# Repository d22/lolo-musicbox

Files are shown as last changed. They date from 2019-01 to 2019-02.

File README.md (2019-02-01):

# Lolo Musicbox
A simple Raspberry Pi NFC musicbox for children, the NFC tags trigger songs or playlists.

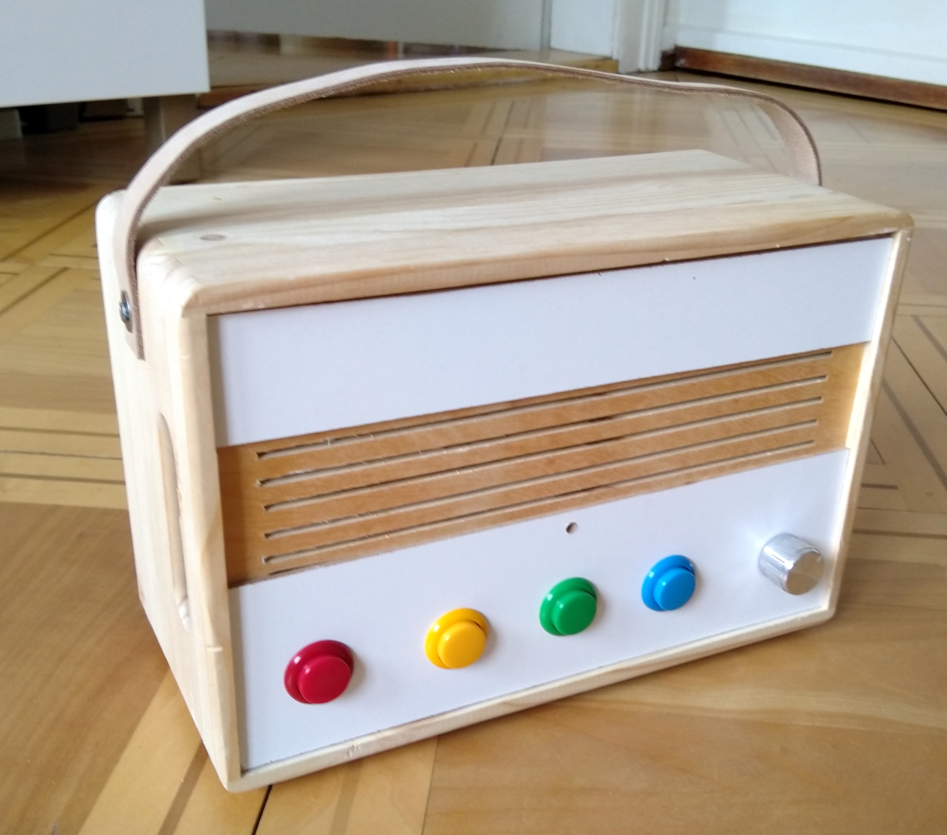
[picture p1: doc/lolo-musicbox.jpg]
lolo-musicbox

Finished product.

lolo-musicbox-inisde
Inside the box.

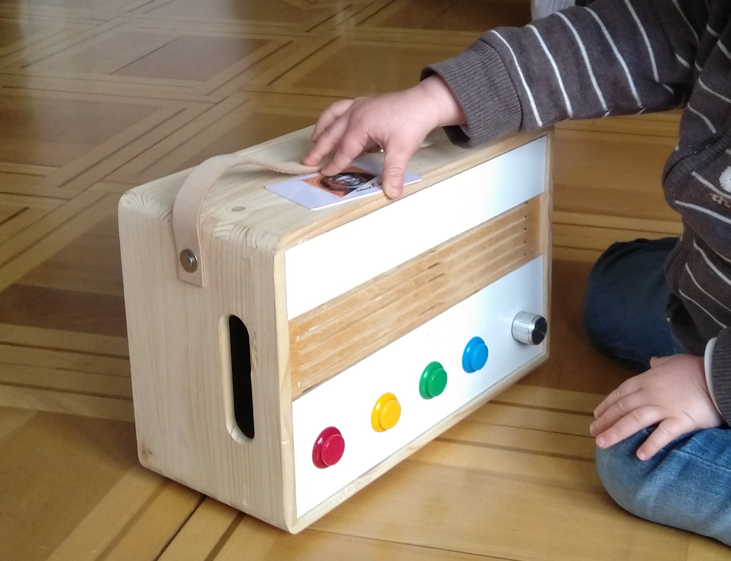
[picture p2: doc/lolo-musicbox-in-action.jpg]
lolo-musicbox-inisde

In action.

## Software Setup
Ten steps to setup the Lolo-Musicbox. Some of them will be explained in detail:
1. Prepare SD with Raspbian
1. Configure WIFI and SSH
1. Boot up the Raspberry Pi, connect via SSH, use raspi-conf for basic setup
1. Install Git
1. Clone this repo
1. Run `setup.sh`
1. check `config.py`
1. Reboot the Raspberry Pi
1. Copy music onto the Lolo-Musicbox
1. Enjoy

### Prepare SD with Raspbian
Tested with 'Raspbian Stretch Lite', see https://www.raspberrypi.org/downloads/raspbian/

### Configure WIFI and SSH
To activate WIFI and SSH without booting the Raspberry Pi add the two files
to the root directory of the SD.

* To activate SSH add an empty file with the name `ssh`
* To configure and activate WIFI add a file with the name `wpa_supplicant.conf`,
containing the WIFI configuration.
```
country=US
ctrl_interface=DIR=/var/run/wpa_supplicant GROUP=netdev
update_config=1

network={
    ssid="<the-ssid-of-your-network>"
    scan_ssid=1
    psk="<the-password-to-your-network>"
    key_mgmt=WPA-PSK
}
```

### Basic setup with raspi-config
```
sudo raspi-config
```
* Change password: 1.
* Set new hostname to 'lolo': 2.N1.
* Don't wait for network on boot: 3.B1. No
* Set locale: 4.I1
* Set WIFI Country: 4.I4

### Install Git
```
sudo apt-get update && sudo apt-get install git
```

### Clone this repo
```
cd ~
git clone <url> lolo
```

### Run `setup.sh`
This installs the required software, registers the Lolo-Musicbox service, and 
tries to optimize the boot time.
``` 
cd ~/lolo
chmod +x setup.sh
./setup.sh
```

### Check `config.py`
All paths and GPIO pins are defined in `config.py`. Just check if the current setup,
hardware and software, matches the given values in `config.py`.

### Copy music onto the Lolo-Musicbox
See 'How the Lolo-Musicbox' works.

### Enjoy
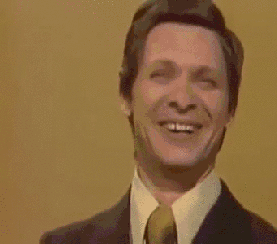
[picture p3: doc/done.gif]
done


## Hardware setup
The musicbox is based on a Raspberry Pi 3+. Additionally I used the following parts:

* MFRC522 RFID/NFC module (library [on Github](https://github.com/ondryaso/pi-rc522))
* MCP3008, 8-Channel 10-Bit ADC to control the volume with a potentiometer 
(see: [Adafruit tutorial](https://learn.adafruit.com/reading-a-analog-in-and-controlling-audio-volume-with-the-raspberry-pi))
* TPA2012, Stereo 2.1W Class D Audio Amplifier (see [Adafruit](https://www.adafruit.com/product/1552))
* 4 arcade buttons
* RGB LED (with according resistors)
* 2 small 4Ω speakers
* 3.5mm audio jack breakout
* 2 NCR18650B LiIon batteries (3.7V)
* TP4056 LiPo battery charger module
* MT3608, DC-DC Step Up Converter, to step up the 3.7V from the batteries to 5V needed by the Raspberry Pi

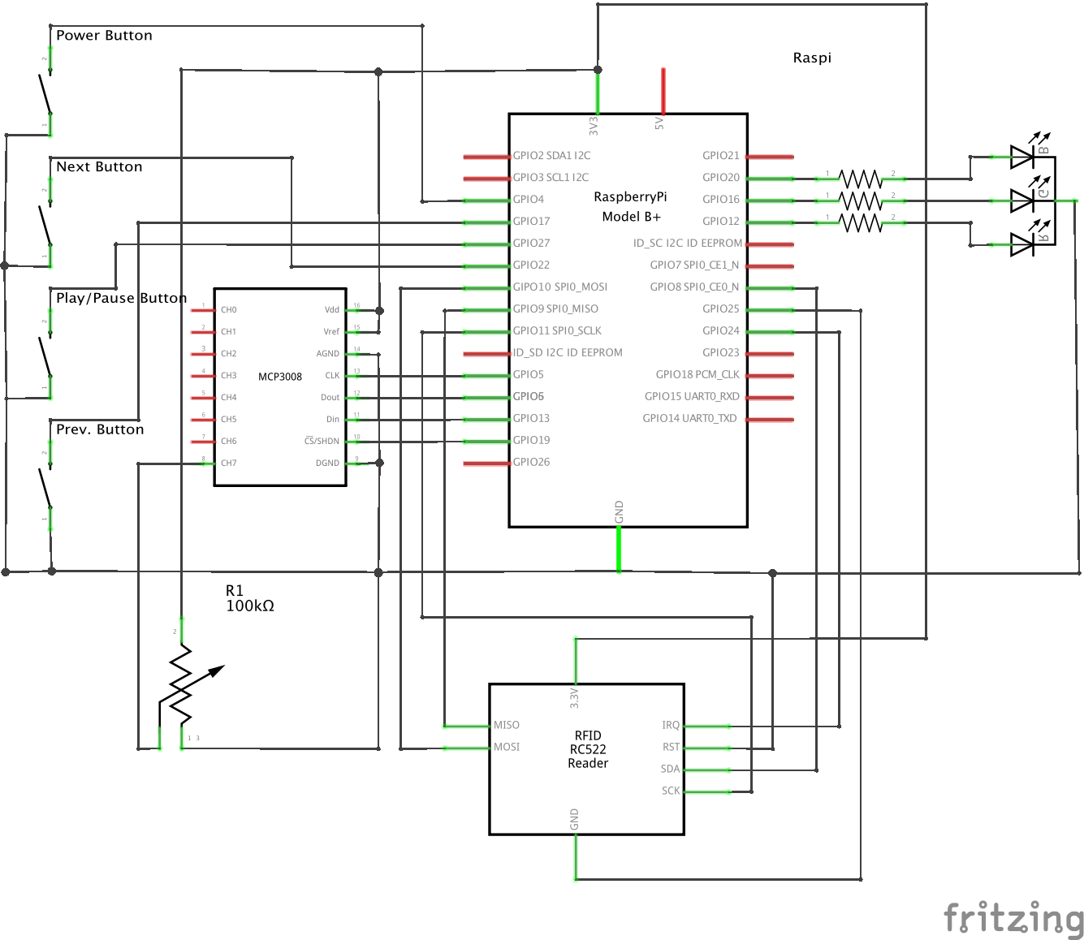
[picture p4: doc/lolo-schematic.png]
Lolo-Musicbox schematic

Please note, that due to a bug in the Fritzing component, the RST and the GND out-pin of the RC522 reader
are switched.

hardware-01

hardware-02

hardware-03

## Issues/Learnings/Things that need improvement
* Rethink the wiring and placement of the parts on the perfboard. Short wires and bad placement makes the placement of the perfboard in the case harder than necessary
* Consider using a digital rotary encoder to set the volume. The potentiometer with the AD converter is not very percise and produces 'volume-jumps' from time to time.
* Add a powerswitch to disconnect the battery from the Raspberry Pi. The battery will be drained, even when the Raspberry is shut down. At least it seems like it does.
* The TP4056 battery charger module supports charging and using the battery at the same time, but if the battery charge is to low, the Raspberry Pi will go into a reboot loop. This must be improved.
* Also, the TP4056 gets quite hot when charging the battery. Consider using a heatsink.
* Boot time is still quite long. After starting the box there is about 20s waiting time without any indication that the musicbox was started. Needs imporvement.
* Async LED blinking and pulsing is hard to control, find cleaner solution.

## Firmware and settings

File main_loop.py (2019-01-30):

import logging
import signal
import sys
import time
import threading

from pirc522 import RFID

import async_button
import mpd_player
import music_copy
import rgb_led
import sound_effect
import usb
from config import LOGGER as LOG_CONF

run = True
rdr = RFID()
util = rdr.util()
util.debug = True

# Logger configuration
logging.basicConfig(level=logging.DEBUG,
                    format=LOG_CONF.LOG_FORMAT,
                    datefmt=LOG_CONF.LOG_DATE_FORMAT,
                    filename=LOG_CONF.LOG_FILE)

log = logging.getLogger(__name__)


def end_read(signal, frame):
    global run
    print("\nCtrl+C captured, ending read.")
    log.info("Ctrl+C captured, ending read.")
    run = False
    player.stop()
    button_stop_event.set()
    time.sleep(2)
    # rgb_led.ready_led_stop_pulse()
    rgb_led.off()
    rdr.cleanup()
    sys.exit()


signal.signal(signal.SIGINT, end_read)

player = mpd_player.Player()
player.stop()
playing_uid = ''
config_mode = False
config_started = False
rgb_led.setup()
rgb_led.ready_pause_led_on()
sound_effect.started()
log.info('************ START ************')


def play_list_on_tag():
    global playing_uid
    global config_mode
    global config_started
    # rdr.wait_for_tag()

    if config_started:
        return

    if usb.has_usb_stick():
        if not config_mode:
            sound_effect.start_config()
            log.info("config mode")
        config_mode = True
        player.stop()
        # rgb_led.ready_led_stop_pulse()
        rgb_led.config_led_on()
    else:
        if config_mode:
            log.info("player mode")
        config_mode = False
        # rgb_led.config_led_stop_blink()
        if player.is_playing():
            rgb_led.ready_led_on()
        else:
            rgb_led.ready_pause_led_on()

    (request_error, data) = rdr.request()
    if not request_error and data is not None:
        (anti_coll_error, uid) = rdr.anticoll()
        if not anti_coll_error:
            dash_uid = "-".join([str(i) for i in uid])
            if config_mode:
                config_started = True
                log.info('config started')
                # rgb_led.config_led_blink()
                rgb_led.copy_led_on()
                music_copy.copy_from_usb(dash_uid)
                sound_effect.end_config()
                # leave config mode when usb stick is removed
                while usb.has_usb_stick():
                    time.sleep(0.08)
                config_started = False
            if dash_uid == playing_uid:
                log.info(dash_uid + " is already selected")
                if not player.is_playing():
                    player.play()
            else:
                log.debug("UID: " + dash_uid)
                log.debug("Registered: " + str(music_copy.is_uid_registered(dash_uid)))

                if music_copy.is_uid_registered(dash_uid):
                    sound_effect.tag_scanned()
                    player.stop()
                    player.load_list(dash_uid)
                    player.play()
                    # rgb_led.ready_led_stop_pulse()
                    rgb_led.ready_led_on()
                    playing_uid = dash_uid


# start button check loop
log.info('Start async_button thread')
main_event = threading.Event()
button_stop_event = async_button.start(main_event)

log.info('start main loop')
while run and not main_event.is_set():
    play_list_on_tag()
    time.sleep(0.08)

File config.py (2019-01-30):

class BUTTON:
    # GPIO Pins, mode GPIO.BOARD
    PAUSE_PIN = 13
    NEXT_PIN = 15
    PREV_PIN = 11
    POWER_PIN = 5
    # button press timeout, dead time before a button press
    # can be registered again
    TIMEOUT = 0.5
    # how long the power button has to be pressed before
    # the raspi is shutdown
    POWER_PRESS_TIME = 5


class LED:
    # Power LED is Pin 8 ()
    # GPIO Pins, mode GPIO.BOARD
    RED_PIN = 32
    GREEN_PIN = 36
    BLUE_PIN = 38

    BLINK_SLEEP = 0.8


class PATHS:
    # make sure this matches the music_directory in /etc/mpd.conf
    # directory must exist
    MUSIC_DIR = '/home/pi/music/'
    # directory must exist
    MOUNT_DIR = '/media/usb_stick'
    # name of the music directory on the usb stick (all mp3 in this dir will be copied)
    MUSIC_SRC_DIR = 'lolo'


class USB:
    # number of lines of the output of 'sudo lsusb'
    # without any usb device connected
    DEFAULT_LSUSB_LINES = 4


class VOLUME:
    # see: https://learn.adafruit.com/raspberry-pi-analog-to-digital-converters/mcp3008
    # and: https://gist.github.com/thijstriemstra/6396142f426aeffb0c1c6507fb2acd7b
    # GPIO Pins, mode GPIO.BCM
    GPIO_CLK = 5  # 29 GPIO.BOARD
    GPIO_MISO = 6  # 31 GPIO.BOARD
    GPIO_MOSI = 13  # 33 GPIO.BOARD
    GPIO_CS = 19  # 35 GPIO.BOARD
    # MCP3008 channel where potentiometer is connected
    MCP3008_CHANNEL = 7
    # The minimum and maximum volumes, as percentages.
    #
    # The default max is less than 100 to prevent distortion. The default min is
    # greater than zero because if your system is like mine, sound gets
    # completely inaudible _long_ before 0%. If you've got a hardware amp or
    # serious speakers or something, your results will vary.
    VOLUME_MIN = 25
    VOLUME_MAX = 95
    # The amount you want one click of the knob to increase or decrease the
    # volume. I don't think that non-integer values work here, but you're welcome
    # to try.
    VOLUME_INCREMENT = 1
    # Audio device name, e.g. 'PCM' or 'Master'. Find with: amixer scontrols
    DEVICE_NAME = 'PCM'


class SOUNDEFFECTS:
    DIR = '/home/pi/lolo/sounds/'
    PLING = 'pling-new.mp3'
    CLIC = 'clic.mp3'
    PRING_DOWN = 'prrring-down-short.mp3'
    PRING_UP = 'prrring-up-short.mp3'
    ZURR = 'zurr.mp3'


class LOGGER:
    LOG_FILE = '/home/pi/lolo/logs/lolo.log'
    LOG_FORMAT = '%(asctime)s - %(name)s - %(levelname)s - %(message)s'
    LOG_DATE_FORMAT = '%y-%m-%d %H:%M:%S'

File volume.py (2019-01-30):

"""
The daemon responsible for changing the volume in response to a turn
of the volume knob.
See: https://gist.github.com/thijstriemstra/6396142f426aeffb0c1c6507fb2acd7b
"""

import logging
import signal
import subprocess
import sys
import time

import Adafruit_MCP3008

from config import VOLUME as CONF

# LOGGING
# ========

logger = logging.getLogger(__name__)

# logging
# logging.basicConfig(
#     level=logging.DEBUG,
#     format='%(asctime)-15s - %(message)s'
# )

# SETTINGS
# ========

DEBUG = False

# Software SPI configuration.
GPIO_CLK = CONF.GPIO_CLK
GPIO_MISO = CONF.GPIO_MISO
GPIO_MOSI = CONF.GPIO_MOSI
GPIO_CS = CONF.GPIO_CS

# MCP3008 channel where potentiometer is connected
MCP3008_CHANNEL = CONF.MCP3008_CHANNEL

# The minimum and maximum volumes, as percentages.
#
# The default max is less than 100 to prevent distortion. The default min is
# greater than zero because if your system is like mine, sound gets
# completely inaudible _long_ before 0%. If you've got a hardware amp or
# serious speakers or something, your results will vary.
VOLUME_MIN = CONF.VOLUME_MIN
VOLUME_MAX = CONF.VOLUME_MAX

# The amount you want one click of the knob to increase or decrease the
# volume. I don't think that non-integer values work here, but you're welcome
# to try.
VOLUME_INCREMENT = CONF.VOLUME_INCREMENT

# Audio device name, e.g. 'PCM' or 'Master'. Find with: amixer scontrols
DEVICE_NAME = CONF.DEVICE_NAME


# (END SETTINGS)
#


def debug(str):
    if not DEBUG:
        return
    logger.debug(str)


class RotaryEncoder(object):
    """
    A class to decode mechanical rotary encoder pulses.
    """

    def __init__(self, gpio_CLK, gpio_CS, gpio_MISO, gpio_MOSI, channel, tolerance=10):
        # MCP3008 component
        self.mcp = Adafruit_MCP3008.MCP3008(clk=gpio_CLK, cs=gpio_CS,
                                            miso=gpio_MISO, mosi=gpio_MOSI)
        self.volume = Volume()
        self.channel = channel

        # to keep from being jittery we'll only change
        # volume when the pot has moved more than 5 'counts'
        self.tolerance = tolerance

        # this keeps track of the last potentiometer value
        self.last_read = 0

    def destroy(self):
        debug('Destroying...')

    def read(self):
        # we'll assume that the pot didn't move
        trim_pot_changed = False

        # read the analog pin
        trim_pot = self.mcp.read_adc(self.channel)

        # how much has it changed since the last read?
        pot_adjust = abs(trim_pot - self.last_read)

        if pot_adjust > self.tolerance:
            trim_pot_changed = True

        if trim_pot_changed:
            # convert 10bit adc0 (0-1024) trim pot read into 0-100 volume level
            set_volume = int(round(trim_pot / 10.24))
            self.volume.set_volume(set_volume)

            # save the potentiometer reading for the next loop
            self.last_read = trim_pot


class VolumeError(Exception):
    pass


class Volume(object):
    """
    A wrapper API for interacting with the volume settings on the RPi.
    """
    MIN = VOLUME_MIN
    MAX = VOLUME_MAX
    INCREMENT = VOLUME_INCREMENT

    def __init__(self):
        # Set an initial value for last_volume in case we're muted when we start.
        self.last_volume = self.MIN
        self._sync()

    def up(self):
        """
        Increases the volume by one increment.
        """
        return self.change(self.INCREMENT)

    def down(self):
        """
        Decreases the volume by one increment.
        """
        return self.change(-self.INCREMENT)

    def change(self, delta):
        v = self.volume + delta
        v = self._constrain(v)
        return self.set_volume(v)

    def set_volume(self, v):
        """
        Sets volume to a specific value.
        """
        self.volume = self._constrain(v)
        debug("set volume: {}".format(self.volume))

        output = self.amixer("set '{}' unmute {}%".format(DEVICE_NAME, v))
        self._sync(output)
        return self.volume

    def toggle(self):
        """
        Toggles muting between on and off.
        """
        if self.is_muted:
            output = self.amixer("set '{}' unmute".format(DEVICE_NAME))
        else:
            # We're about to mute ourselves, so we should remember the last volume
            # value we had because we'll want to restore it later.
            self.last_volume = self.volume
            output = self.amixer("set '{}' mute".format(DEVICE_NAME))

        self._sync(output)
        if not self.is_muted:
            # If we just unmuted ourselves, we should restore whatever volume we
            # had previously.
            self.set_volume(self.last_volume)
        return self.is_muted

    def status(self):
        if self.is_muted:
            return "{}% (muted)".format(self.volume)
        return "{}%".format(self.volume)

    # Read the output of `amixer` to get the system volume and mute state.
    #
    # This is designed not to do much work because it'll get called with every
    # click of the knob in either direction, which is why we're doing simple
    # string scanning and not regular expressions.
    def _sync(self, output=None):
        if output is None:
            output = self.amixer("get '{}'".format(DEVICE_NAME))

        lines = output.readlines()
        if DEBUG:
            strings = [line.decode('utf8') for line in lines]
            debug("OUTPUT:")
            debug("".join(strings))
        last = lines[-1].decode('utf-8')

        # The last line of output will have two values in square brackets. The
        # first will be the volume (e.g., "[95%]") and the second will be the
        # mute state ("[off]" or "[on]").
        i1 = last.rindex('[') + 1
        i2 = last.rindex(']')

        self.is_muted = last[i1:i2] == 'off'

        i1 = last.index('[') + 1
        i2 = last.index('%')
        # In between these two will be the percentage value.
        pct = last[i1:i2]

        self.volume = int(pct)

    # Ensures the volume value is between our minimum and maximum.
    def _constrain(self, v):
        if v < self.MIN:
            return self.MIN
        if v > self.MAX:
            return self.MAX
        return v

    def amixer(self, cmd):
        p = subprocess.Popen("amixer {}".format(cmd), shell=True, stdout=subprocess.PIPE)
        code = p.wait()
        if code != 0:
            raise VolumeError("Unknown error: {}".format(code))
            sys.exit(0)

        return p.stdout
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
